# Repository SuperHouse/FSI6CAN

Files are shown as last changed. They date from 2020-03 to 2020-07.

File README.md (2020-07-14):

Flysky FS-i6 CAN Interface
==========================

Mounts inside a Flysky FS-i6 remote control transmitter to provide a
CAN bus interface for external control, so it can send and receive
commands from external input devices. This replaces the control normally
done using the built-in joysticks.

Intended for use with the Chair Breakout Mini, which interfaces with
assistive input devices including wheelchair joysticks and button
boxes and gives them a CAN bus interface.

This allows the wheelchair controls to be used to fly a drone or R/C
plane, or drive an R/C car.

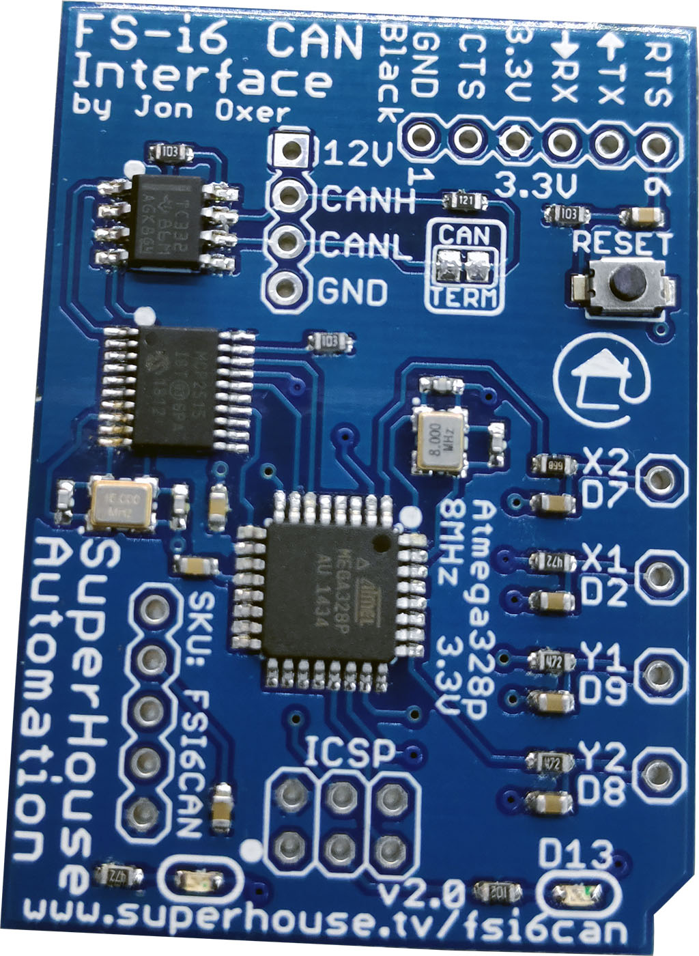
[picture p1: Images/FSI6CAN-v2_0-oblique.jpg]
FS-i6 CAN Interface


Features:

 * Takes power from transmitter header.
 * CAN bus.
 * ATmega328 MCU (Arduino compatible)

More information is available at:

  https://www.superhouse.tv/fsi6can

Hardware
--------
The "Hardware" directory contains the PCB design as an EAGLE project.
EAGLE PCB design software is available from Autodesk free for
non-commercial use.

Firmware
--------
The "Firmware" directory contains example firmware as an Arduino
project.

Credits
-------
Jonathan Oxer <jon@oxer.com.au>

License
-------
Copyright 2018-2020 SuperHouse Automation Pty Ltd  www.superhouse.tv  

The hardware portion of this project is licensed under the TAPR Open
Hardware License (www.tapr.org/OHL). The "license" folder within this
repository contains a copy of this license in plain text format.

The software portion of this project is licensed under the Simplified
BSD License. The "licence" folder within this project contains a
copy of this license in plain text format.

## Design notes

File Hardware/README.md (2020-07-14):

Flysky FS-i6 CAN Interface
==========================
Copyright 2018-2019 SuperHouse Automation Pty Ltd <www.superhouse.tv>  
Designed by Jonathan Oxer

Mounts inside a Flysky FS-i6 remote control transmitter to provide a
CAN bus interface for external control.

Features:

 * Takes power from transmitter header.
 * CAN bus.

More information is available at:

  http://www.superhouse.tv/fsi6can

INSTALLATION
------------
The design is saved as an EAGLE project. EAGLE PCB design software is
available from www.cadsoftusa.com free for non-commercial use. To use
this project download it and place the directory containing these files
into the "eagle" directory on your computer. Then open EAGLE and
navigate to the project.

DISTRIBUTION
------------
The specific terms of distribution of this project are governed by the
license referenced below.

LICENSE
-------
Licensed under the TAPR Open Hardware License (www.tapr.org/OHL).
The "license" folder within this repository also contains a copy of
this license in plain text format.

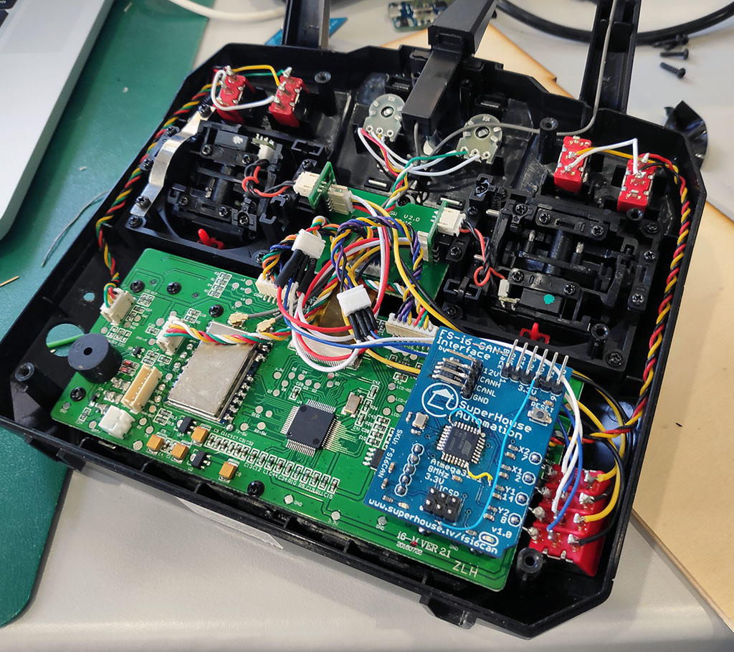
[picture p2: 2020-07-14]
Images/FSI6CAN-v1_0-fitted.jpg

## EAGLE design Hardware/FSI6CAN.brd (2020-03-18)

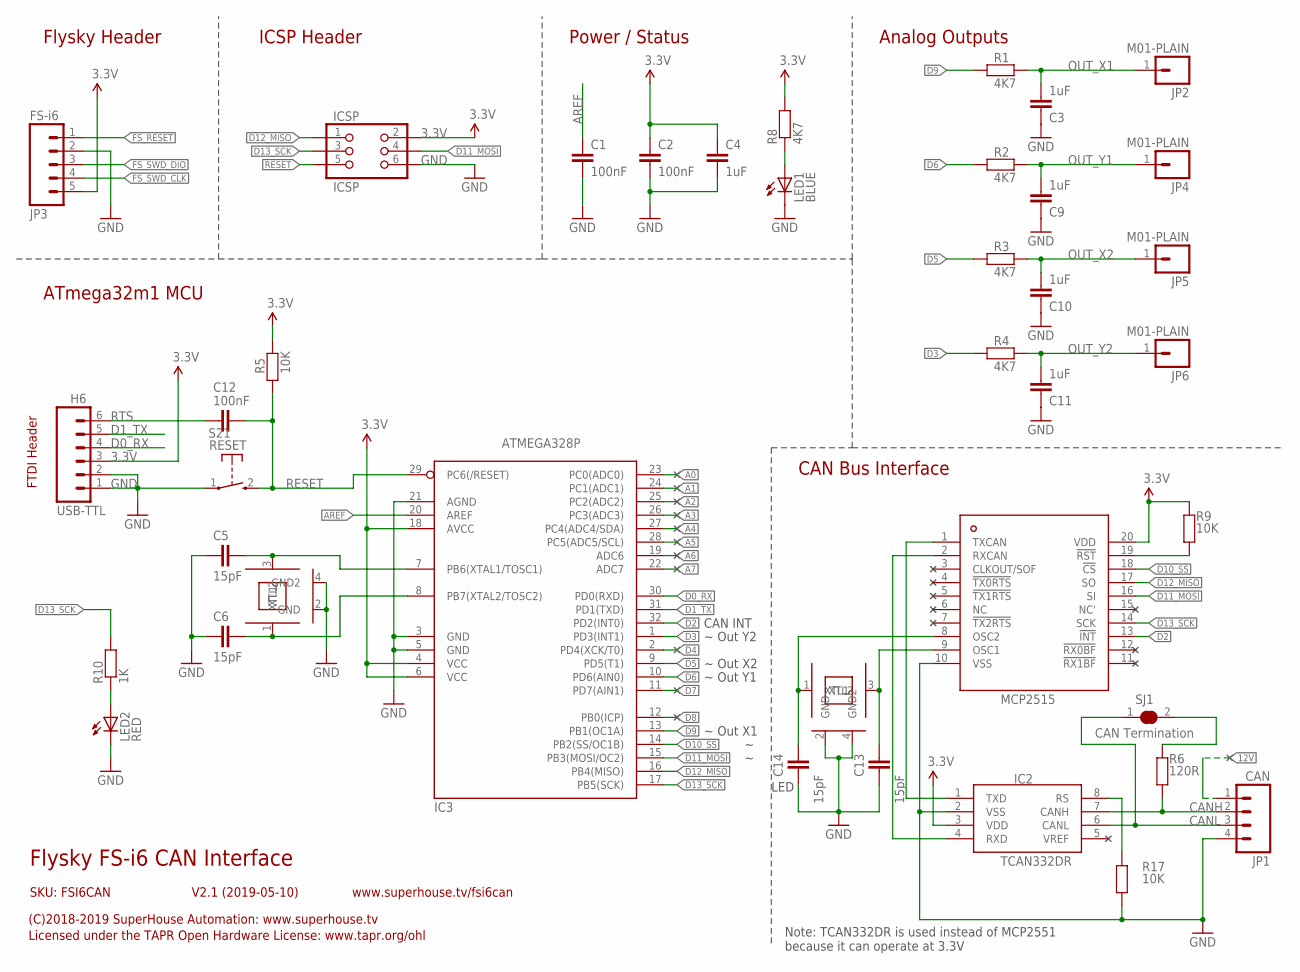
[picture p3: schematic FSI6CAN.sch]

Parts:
C1, C2, C12: 100nF; C0603
C3, C4, C9, C10, C11: 1uF; C0603
C5, C6, C13, C14: 15pF; C0603
H6: USB-TTL; 1X06-P-RA
IC2: TCAN332DR; SO08
IC3: ATMEGA328P; TQFP32-08
IC4: MCP2515; TSSOP20
ICSP: ICSP; 2X03-ICSP
JP1: CAN; 1X04-P
JP2, JP4, JP5, JP6: M01-PLAIN; 1X01
JP3: FS-i6; 1X05
LED1: BLUE; LED-0603
LED2: RED; LED-0603
R1, R2, R3, R4, R8: 4K7; R0603
R5, R9, R17: 10K; R0603
R6: 120R; R0603
R10: 1K; R0603
S21: RESET; TACTILE_SMT_3X4X2
SJ1: CAN Termination; SJC
XTL1: 8MHz; CRYSTAL-SMD-3X2
XTL3: 16MHz; CRYSTAL-SMD-3X2

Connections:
3.3V: C2.1, C4.1, H6.3, IC2.3 (VDD), IC3.4 (VCC), IC3.6 (VCC), IC3.18 (AVCC), IC4.20 (VDD), ICSP.2, JP3.5, R5.1, R8.2, R9.2
12V: JP1.1
A0: IC3.23 (PC0(ADC0))
A1: IC3.24 (PC1(ADC1))
A2: IC3.25 (PC2(ADC2))
A3: IC3.26 (PC3(ADC3))
A4: IC3.27 (PC4(ADC4/SDA))
A5: IC3.28 (PC5(ADC5/SCL))
A6: IC3.19 (ADC6)
A7: IC3.22 (ADC7)
AREF: C1.1, IC3.20 (AREF)
CANH: IC2.7 (CANH), JP1.2, R6.1
CANL: IC2.6 (CANL), JP1.3, SJ1.1
D0_RX: H6.4, IC3.30 (PD0(RXD))
D1_TX: H6.5, IC3.31 (PD1(TXD))
D2: IC3.32 (PD2(INT0)), IC4.13 (!INT)
D3: IC3.1 (PD3(INT1)), R4.1
D4: IC3.2 (PD4(XCK/T0))
D5: IC3.9 (PD5(T1)), R3.1
D6: IC3.10 (PD6(AIN0)), R2.1
D7: IC3.11 (PD7(AIN1))
D8: IC3.12 (PB0(ICP))
D9: IC3.13 (PB1(OC1A)), R1.1
D10_SS: IC3.14 (PB2(SS/OC1B)), IC4.18 (!CS)
D11_MOSI: IC3.15 (PB3(MOSI/OC2)), IC4.16 (SI), ICSP.4
D12_MISO: IC3.16 (PB4(MISO)), IC4.17 (SO), ICSP.1
D13_SCK: IC3.17 (PB5(SCK)), IC4.14 (SCK), ICSP.3, R10.2
FS_RESET: JP3.1
FS_SWD_CLK: JP3.4
FS_SWD_DIO: JP3.3
GND: C1.2, C2.2, C3.2, C4.2, C5.1, C6.1, C9.2, C10.2, C11.2, C13.1, C14.1, H6.1, H6.2, IC2.2 (VSS), IC3.3 (GND), IC3.5 (GND), IC3.21 (AGND), IC4.10 (VSS), ICSP.6, JP1.4, JP3.2, LED1.C, LED2.C, R17.1, S21.1, XTL1.2 (GND), XTL1.4 (GND2), XTL3.2 (GND), XTL3.4 (GND2)
unnamed: LED2.A, R10.1
unnamed: R6.2, SJ1.2
unnamed: IC2.1 (TXD), IC4.1 (TXCAN)
unnamed: LED1.A, R8.1
unnamed: IC2.4 (RXD), IC4.2 (RXCAN)
unnamed: C13.2, IC4.9 (OSC1), XTL3.3 (XTL2)
unnamed: C14.2, IC4.8 (OSC2), XTL3.1 (XTL1)
unnamed: C5.2, IC3.7 (PB6(XTAL1/TOSC1)), XTL1.3 (XTL2)
unnamed: C6.2, IC3.8 (PB7(XTAL2/TOSC2)), XTL1.1 (XTL1)
unnamed: IC2.8 (RS), R17.2
unnamed: IC4.19 (!RST), R9.1
OUT_X1: C3.1, JP2.1, R1.2
OUT_X2: C10.1, JP5.1, R3.2
OUT_Y1: C9.1, JP4.1, R2.2
OUT_Y2: C11.1, JP6.1, R4.2
RESET: C12.2, IC3.29 (PC6(/RESET)), ICSP.5, R5.2, S21.2 (S)
RTS: C12.1, H6.6

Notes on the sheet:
ATmega32m1 MCU
Flysky FS-i6 CAN Interface
V2.1 (2019-05-10)
SKU: FSI6CAN
(C)2018-2019 SuperHouse Automation: www.superhouse.tv
Licensed under the TAPR Open Hardware License: www.tapr.org/ohl
www.superhouse.tv/fsi6can
Power / Status
FTDI Header
Flysky Header
Analog Outputs
CAN Bus Interface
ICSP Header
~ Out Y2
~ Out X2
~ Out Y1
LED
Note: TCAN332DR is used instead of MCP2551 because it can operate at 3.3V
CAN INT
~ Out X1

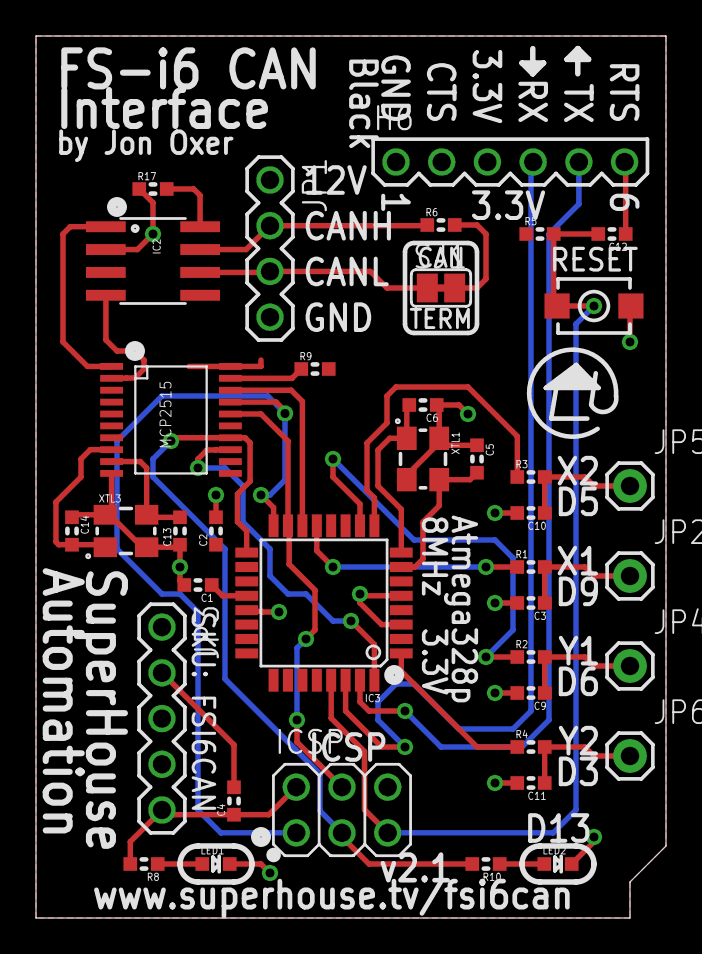
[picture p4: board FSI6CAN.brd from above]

Board: 2 copper layers, 35.0 x 49.0 mm, 39 parts (0 on the bottom side), 33 nets.

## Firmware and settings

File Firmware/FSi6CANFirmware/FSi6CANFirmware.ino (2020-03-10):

/**
   Firmware for the FSI6CAN CAN interface for the Flysky FSi6 transmitter.
   Version: 2.2.

   Receives messages via CAN bus and generates analog outputs.

   By Chris Fryer (chris.fryer78@gmail.com) and Jonathan Oxer (jon@oxer.com.au)
   www.superhouse.tv
   
   In the Arduino IDE, select board profile:
    -> Arduino Pro or Pro Mini
      -> ATmega328P (3.3V, 8MHz)

   External dependency, available in the Arduino library manager:
     "CAN" by Sandeep Mistry
*/

/*--------------------------- Configuration ------------------------------*/
// Configuration should be done in the included file:
#include "config.h"

/*--------------------------- Libraries ----------------------------------*/
#include <CAN.h>    // CAN bus: https://github.com/sandeepmistry/arduino-CAN

/*--------------------------- Global Variables ---------------------------*/
/* Mode 1 */
#if JOYSTICK_MODE == 1
const uint8_t g_output_rudder   = X1_OUTPUT_PIN;  // Rudder
const uint8_t g_output_elevator = Y1_OUTPUT_PIN;  // Elevator
const uint8_t g_output_ailerons = X2_OUTPUT_PIN;  // Ailerons
const uint8_t g_output_throttle = Y2_OUTPUT_PIN;  // Throttle
#endif

/* Mode 2 */
#if JOYSTICK_MODE == 2
const uint8_t g_output_rudder   = X1_OUTPUT_PIN;  // Rudder
const uint8_t g_output_elevator = Y2_OUTPUT_PIN;  // Elevator
const uint8_t g_output_ailerons = X2_OUTPUT_PIN;  // Ailerons
const uint8_t g_output_throttle = Y1_OUTPUT_PIN;  // Throttle
#endif

/* Mode 3 */
#if JOYSTICK_MODE == 3
const uint8_t g_output_rudder   = X2_OUTPUT_PIN;  // Rudder
const uint8_t g_output_elevator = Y1_OUTPUT_PIN;  // Elevator
const uint8_t g_output_ailerons = X1_OUTPUT_PIN;  // Ailerons
const uint8_t g_output_throttle = Y2_OUTPUT_PIN;  // Throttle
#endif

/* Mode 4 */
#if JOYSTICK_MODE == 4
const uint8_t g_output_rudder   = X2_OUTPUT_PIN;  // Rudder
const uint8_t g_output_elevator = Y2_OUTPUT_PIN;  // Elevator
const uint8_t g_output_ailerons = X1_OUTPUT_PIN;  // Ailerons
const uint8_t g_output_throttle = Y1_OUTPUT_PIN;  // Throttle
#endif

uint8_t g_x1_value          = MIN_OUTPUT_VALUE;
uint8_t g_y1_value          = MIN_OUTPUT_VALUE;
uint8_t g_x2_value          = MIN_OUTPUT_VALUE;
uint8_t g_y2_value          = MAX_OUTPUT_VALUE;   // Maximum output is stick full down (throttle off)
uint8_t g_throttle_position = MAX_OUTPUT_VALUE;   // Maximum output is stick full down (throttle off)
char    g_incoming_message_buffer[12];            // Buffer for incoming CAN messages

// Serial
uint32_t g_last_serial_report_time = 0;           // Timestamp of last report to serial console

/*--------------------------- Function Signatures ---------------------------*/
void onReceive(int16_t packet_size);

/*--------------------------- Instantiate Global Objects --------------------*/
// None

/*--------------------------- Program ---------------------------------------*/
/**
  Setup
*/
void setup() {
  Serial.begin(SERIAL_BAUD_RATE);
  Serial.println("FSi6 CAN bus interface v2.2");
  Serial.println("Starting CAN Receiver");

  // start the CAN bus at 500 kbps
  if (!CAN.begin(500E3)) {
    Serial.println("Starting CAN failed!");
    while (1);
  } else {
    Serial.println("Started CAN OK");
  }

  // register the receive callback
  CAN.onReceive(onReceive);

  // Set up analog outputs
  pinMode(g_output_rudder,   OUTPUT);
  pinMode(g_output_elevator, OUTPUT);
  pinMode(g_output_ailerons, OUTPUT);
  pinMode(g_output_throttle, OUTPUT);

  analogWrite(g_output_rudder,   0);
  analogWrite(g_output_elevator, 0);
  analogWrite(g_output_ailerons, 0);
  analogWrite(g_output_throttle, MAX_OUTPUT_VALUE);  // This is to hold right stick down to allow Tx to start

  delay(100);
}

/**
  Loop
*/
void loop() {
  g_y2_value = g_throttle_position;

  analogWrite(g_output_rudder,   g_x1_value);
  analogWrite(g_output_elevator, g_y1_value);
  analogWrite(g_output_ailerons, g_x2_value);
  analogWrite(g_output_throttle, g_y2_value);

  if (OUTPUT_DEBUG)
  {
    uint32_t current_time = millis();
    if (current_time > (g_last_serial_report_time + g_serial_telemetry_period))
    {
      //Serial.print(xAxis1ReportValue);
      //Serial.print(" | ");
      Serial.print("X1:");
      Serial.print(g_x1_value);

      Serial.print(" |Y1:");
      Serial.print(g_y1_value);

      Serial.print(" |X2:");
      Serial.print(g_x2_value);

      Serial.print(" |Y2:");
      Serial.print(g_y2_value);

      Serial.println(" |");
      g_last_serial_report_time = current_time;
    }
  }
}

/**
  Callback when a CAN packet arrives
*/
void onReceive(int16_t packet_size) {
  // Received a packet. We're not using packet_size at the moment. Just work
  // through all incoming bytes.

  int integer_value = 0;    // throw away previous integer_value
  char incoming_byte;
  byte is_negative = 0;
  uint8_t i = 0;
  if (CAN_DEBUG)
  {
    Serial.print("ID: 0x");
    Serial.print(CAN.packetId(), HEX);
    Serial.print(" Value: ");
  }
  while (CAN.available()) {
    incoming_byte = (char)CAN.read();
    if (CAN_DEBUG)
    {
      Serial.print(incoming_byte - 48);
    }
    g_incoming_message_buffer[i] = incoming_byte;
    i++;
    if (incoming_byte == '-')
    {
      is_negative = true;
    } else {
      integer_value *= 10;  // shift left 1 decimal place
      // convert ASCII to integer, add, and shift left 1 decimal place
      integer_value = ((incoming_byte - 48) + integer_value);
    }
  }
  if (CAN_DEBUG)
  {
    Serial.println("");
  }


  if (is_negative)
  {
    integer_value = integer_value * -1;
  }

  int axis_output = 0;
  // only print packet data for non-RTR packets
  if (CAN.packetId() == 0x12) // Packet ID 0x12 for X axis
  {
    if (CAN_DEBUG)
    {
      Serial.print("X=");
      Serial.print(integer_value, DEC);
    }
    if (INVERT_X1)
    {
      axis_output = map(integer_value, +75, -75, MIN_OUTPUT_VALUE, MAX_OUTPUT_VALUE);
    } else {
      axis_output = map(integer_value, -75, +75, MIN_OUTPUT_VALUE, MAX_OUTPUT_VALUE);
    }
    g_x1_value = constrain(axis_output, MIN_OUTPUT_VALUE, MAX_OUTPUT_VALUE);
  }

  if (CAN.packetId() == 0x13) // Packet ID 0x13 for Y axis
  {
    if (CAN_DEBUG)
    {
      Serial.print("     Y=");
      Serial.println(integer_value, DEC);
    }
    //g_y1_value = integer_value;
    if (INVERT_Y1)
    {
      axis_output = map(integer_value, +75, -75, MIN_OUTPUT_VALUE, MAX_OUTPUT_VALUE);
    } else {
      axis_output = map(integer_value, -75, +75, MIN_OUTPUT_VALUE, MAX_OUTPUT_VALUE);
    }
    g_y1_value = constrain(axis_output, MIN_OUTPUT_VALUE, MAX_OUTPUT_VALUE);
  }

  if (CAN.packetId() == 0x14) // Packet ID 0x14 for buttons
  {
    if (CAN_DEBUG)
    {
      Serial.print("CAN key: ");
      Serial.println(g_incoming_message_buffer[0]);
    }
    // Check for specific keys to use for throttle up and down
    if (g_incoming_message_buffer[0] == 'w' && g_incoming_message_buffer[1] == '+') // Throttle up
    {
      if (INVERT_Y2)
      {
        if (g_throttle_position < THROTTLE_INCREMENT) // Bounds checking to prevent <0
        {
          g_throttle_position = MIN_OUTPUT_VALUE;
        } else {
          g_throttle_position = g_throttle_position - THROTTLE_INCREMENT;
        }
      } else {
        if (g_throttle_position > (MAX_OUTPUT_VALUE - THROTTLE_INCREMENT)) // Bounds checking to prevent >255
        {
          g_throttle_position = MAX_OUTPUT_VALUE;
        } else {
          g_throttle_position = g_throttle_position + THROTTLE_INCREMENT;
        }
      }
    }

    if (g_incoming_message_buffer[0] == 'v' && g_incoming_message_buffer[1] == '+') // Throttle down
    {
      if (INVERT_Y2)
      {
        if (g_throttle_position > (MAX_OUTPUT_VALUE - THROTTLE_INCREMENT)) // Bounds checking to prevent >255
        {
          g_throttle_position = MAX_OUTPUT_VALUE;
        } else {
          g_throttle_position = g_throttle_position + THROTTLE_INCREMENT;
        }
      } else {
        if (g_throttle_position < THROTTLE_INCREMENT) // Bounds checking to prevent <0
        {
          g_throttle_position = MIN_OUTPUT_VALUE;
        } else {
          g_throttle_position = g_throttle_position - THROTTLE_INCREMENT;
        }
      }
    }

    if (OUTPUT_DEBUG)
    {
      Serial.print("New throttle position: ");
      Serial.println(g_throttle_position);
    }
  }
}

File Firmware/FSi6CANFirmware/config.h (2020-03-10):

/* ----------------- General config -------------------------------- */
/* Joystick arrangement */
#define JOYSTICK_MODE       3         // 1, 2, 3, or 4
#define INVERT_X1        true
#define INVERT_Y1        true
#define INVERT_X2       false
#define INVERT_Y2        true

/* Ratcheting throttle */
#define THROTTLE_INCREMENT 30
//#define THROTTLE_STALL_POINT 135   // Values above this, the motor won't turn properly

/* Serial */
#define   SERIAL_BAUD_RATE          115200       // Speed for USB serial console
uint32_t  g_serial_telemetry_period  = 500;      // Serial report interval in milliseconds

/* Debugging */
#define CAN_DEBUG       false
#define OUTPUT_DEBUG    false

/* ----------------- Hardware-specific config ---------------------- */
/* Analog outputs to Flysky transmitter */
const uint8_t X1_OUTPUT_PIN = 3;  // Red
const uint8_t Y1_OUTPUT_PIN = 6;  // Orange
const uint8_t X2_OUTPUT_PIN = 9;  // Black
const uint8_t Y2_OUTPUT_PIN = 5;  // Brown

// Don't output more than this using PWM. Scale to make this 100% output
#define MAX_OUTPUT_VALUE  255
#define MID_OUTPUT_VALUE  127
#define MIN_OUTPUT_VALUE    0

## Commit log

2020-02-21 Added support for changing throttle using keystrokes
2020-02-28 Increased throttle increment
2020-03-10 Major change to add joystick modes and throttle bounds checking
2020-03-18 Fixed value of R10
    [FSI6CAN.brd, FSI6CAN.sch]
2020-07-14 Moved files for project restructure
    [FSI6CAN.brd, FSI6CAN.sch]

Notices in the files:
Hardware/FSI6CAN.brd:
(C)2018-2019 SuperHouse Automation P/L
